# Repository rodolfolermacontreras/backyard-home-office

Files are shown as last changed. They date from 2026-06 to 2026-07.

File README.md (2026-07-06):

# Autonomous WorkPod

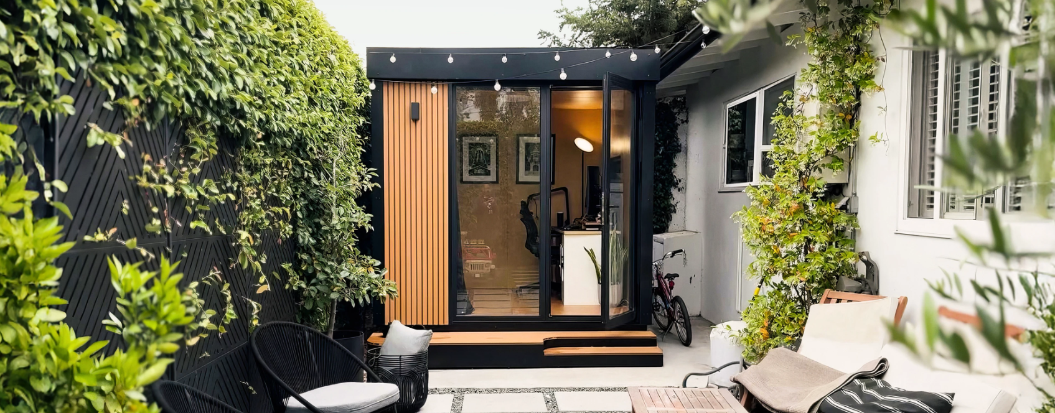
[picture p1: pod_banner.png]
Autonomous WorkPod


Your office is 5 steps from the house. Plug one cable, skip permits, enter deep work.

## What is this?

Open hardware for a backyard office pod. Below permit threshold. One plug. No slab.

Whether you're learning, customizing, or building your own version — the files are here.

## 👶 New to building? Start with the Beginner Guide

If you've never built anything, don't start with the CAD files. Start here:
**[guide/README.md](guide/README.md)** — plain-English checklists, step-by-step build,
schematics, and an El Paso, TX permit + shopping guide.

## Pod Lineup

| | [WorkPod Core](cad/pod-core/) | [WorkPod Pro](cad/pod-pro/) | [WorkPod Versatile](cad/pod-versatile/) |
|---|---|---|---|
| Floor area | 80 sqft | 102 sqft | 105 sqft |
| Ceiling height | 7.25' flat | 6.8'–9.3' sloped | 7.25' flat |
| Foundation | 4 adjustable feet | 6 adjustable feet | 6 adjustable feet |
| Weight capacity | 2.3 tons | 2.9 tons | 2.9 tons |
| Outlets | 2 wall | 2 wall + 1 floor | 5 wall |
| Lighting | 1 ceiling light | 1 ceiling light | 4 ceiling lights |
| Ethernet | 2 ports | — | 2 ports |
| Ventilator | — | Yes | Yes |
| Glass walls | 1 | 1 | 3 |
| Comfort range | — | 45–100°F | 45–100°F |
| Installation | 1–2 days | 1–2 days | 1–2 days |

All models: single outdoor cable from house, no excavation, no concrete, 5° slope tolerance, 7-layer wall system.

## Repo Layout

```
cad/                  3D design files
  pod-pro/            WorkPod Pro
    step/             STEP files (opens in any CAD tool)
    stl/              STL files for 3D printing
  pod-versatile/      WorkPod Versatile
    step/
    stl/
  pod-core/           WorkPod Core
    step/
    stl/

electronics/          Electrical system
  bom/                Electronics parts list

bom/                  Full bill of materials (all parts, prices, links)
```

## Big Files: Git LFS

This repo uses **Git LFS** for CAD, STL, STEP, PCB, video, and PDF files.
Install LFS once before cloning or pushing:

```bash
brew install git-lfs     # macOS
git lfs install
git clone https://github.com/autonomous-ai/autonomous-pod.git
```

## Want to Contribute?

- Upload CAD to [cad/](cad/) with STEP export
- Open an Issue if something is broken or unclear

See [CONTRIBUTING.md](CONTRIBUTING.md) for details.

## License

- Hardware, CAD, docs — **[CC BY-NC-SA 4.0](LICENSE)**
- Firmware, code — **[PolyForm Noncommercial 1.0.0](LICENSE-CODE)**

Plain-English summary: **[LICENSE.md](LICENSE.md)**

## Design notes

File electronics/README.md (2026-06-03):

# Electronics

Electrical system for the WorkPod Pro.

## System Overview

One outdoor cable runs from the house. Inside:
- 3 grounded wall outlets
- 1 ceiling light (LED)
- 1 ventilator (120V)
- 2 Ethernet ports (pass-through to home network)

Optional: solar panel roof add-on with charge controller.

## Files

`bom/parts.csv` — electronics components list

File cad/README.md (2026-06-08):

# CAD

3D design files for all pod variants.

## Folders

```
pod-pro/          WorkPod Pro
  step/           STEP exports (opens in any CAD tool)
  stl/            STL exports for 3D printing
pod-versatile/    Pod Versatile (Studio Pod)
  step/
  stl/
pod-core/         Pod Core
  step/
  stl/
```

## File Naming

`part-name_v1.stp`, `panel-exterior-left_v2.stl`

## Contributing CAD

- Always export and upload `.stp` to the relevant `step/` folder
- Export `.stl` to the relevant `stl/` folder for 3D printing

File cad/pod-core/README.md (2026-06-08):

# WorkPod Core — CAD Files

Compact backyard office. Simple, distraction-free workspace.

| | |
|---|---|
| Floor area | 80 sqft |
| Ceiling height | 7.25' flat |
| Foundation | 4 adjustable feet, 5° slope |
| Weight capacity | 2.3 tons |
| Electrical | 2 wall outlets, 1 ceiling light, 2 Ethernet ports |
| Installation | 1–2 days, no slab required |

## Folders

- `step/` — STEP files (opens in Fusion 360, FreeCAD, SolidWorks, etc.)
- `stl/` — STL files for 3D printing or previewing

## Parts

| File | Description |
|---|---|
| `workpod-mini-assembly` | Full assembly |
| `adjustable-base` | Foundation adjustable foot base |
| `door` | Door assembly |
| `floor-bar-back` | Floor frame — back bar |
| `floor-bar-front` | Floor frame — front bar |
| `floor-bar-side` | Floor frame — side bar |
| `floor-bar-support` | Floor frame — support bar |
| `floor-side-left` | Floor frame — left side panel |
| `floor-side-right` | Floor frame — right side panel |
| `wall-glass` | Glass wall panel |
| `wall-cluster-back-1` | Back wall cluster 1 |
| `wall-cluster-back-2` | Back wall cluster 2 |
| `wall-cluster-front` | Front wall cluster |
| `wall-cluster-left-1` | Left wall cluster 1 |
| `wall-cluster-left-2` | Left wall cluster 2 |
| `wall-cluster-right-1` | Right wall cluster 1 |
| `wall-cluster-right-2` | Right wall cluster 2 |
| `roof-cluster` | Roof cluster (main) |
| `roof-cluster-1` | Roof cluster 1 |
| `roof-cluster-2` | Roof cluster 2 |
| `roof-frame-front` | Roof frame — front |
| `roof-frame-left` | Roof frame — left |
| `roof-frame-right` | Roof frame — right |
| `panel-pu-alu` | PU aluminium cladding panel |
| `picomat-back` | Picomat foundation — back |
| `picomat-front-left` | Picomat foundation — front left |
| `picomat-front-right` | Picomat foundation — front right |
| `outdoor-light` | Outdoor light fixture |
| `outlet-cover` | Outlet cover plate |
| `step-outdoor` | Outdoor step |
| `vent-cover` | Ventilation cover |

## File Naming

`part-name_v1.stp` / `part-name_v1.stl`

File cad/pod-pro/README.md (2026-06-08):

# WorkPod Pro — CAD Files

Mid-sized backyard office. More room to stretch out, sloped ceiling, premium design.

| | |
|---|---|
| Floor area | 102 sqft |
| Ceiling height | 6.8'–9.3' sloped |
| Foundation | 6 adjustable feet, 5° slope |
| Weight capacity | 2.9 tons |
| Comfort range | 45–100°F |
| Electrical | 2 wall outlets, 1 floor outlet, 1 ceiling light, 1 ventilator |
| Extras | Built-in bookshelf |
| Installation | 1–2 days, no slab required |

## Folders

- `step/` — STEP files (opens in Fusion 360, FreeCAD, SolidWorks, etc.)
- `stl/` — STL files for 3D printing or previewing

## Parts

| Group | Files |
|---|---|
| Frames | `frame-main/front/back/left-a/left-b/right-a/right-b/steel_v1` |
| Floor panels | `floor-panel-a/b/c_v1` |
| Wall panels | `wall-back-a/b/c_v1`, `wall-left-a/b/c/d_v1`, `wall-right-a/b/c_v1` |
| Roof panels | `roof-panel-a/b/c/d_v1` |
| Door | `door-assembly_v1` |
| Foundation | `foundation-post-base_v1` |
| Cladding | `cover-composite_v1`, `vinyl-cladding_v1`, `trim-metal_v1` |
| Electrical | `electrical-cabinet_v1` |
| Furniture | `furniture-bookshelf_v1` |

## File Naming

`part-name_v1.stp` / `part-name_v1.stl`

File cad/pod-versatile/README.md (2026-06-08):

# WorkPod Versatile — CAD Files

Large creative studio. Three full glass walls, maximum light, configured as a backyard homelab or studio.

| | |
|---|---|
| Floor area | 105 sqft |
| Ceiling height | 7.25' flat |
| Foundation | 6 adjustable feet, 5° slope |
| Weight capacity | 2.9 tons |
| Comfort range | 45–100°F |
| Electrical | 5 wall outlets, 4 ceiling lights, 2 Ethernet ports, 1 ventilator |
| Glass walls | 3 full glass walls |
| Installation | 1–2 days, no slab required |

## Folders

- `step/` — STEP files (opens in Fusion 360, FreeCAD, SolidWorks, etc.)
- `stl/` — STL files for 3D printing or previewing

## Parts

| Group | Files |
|---|---|
| Full assembly | `studio-pod-assembly_v1` |
| Foundation | `foundation-adjustable-base_v1` |
| Floor base frames | `floor-base-frame-main/back/front/mid/left-a/left-b/right-a/right-b_v1` |
| Floor panels | `floor-panel-a/b/c_v1` |
| Ceiling panels | `ceiling-panel-1/2/3_v1` |
| Roof panels | `roof-panel-a/b/c_v1`, `roof-bitumen_v1` |
| Roof frames | `roof-frame-1/2_v1`, `roof-frame-rod-1/2_v1` |
| Walls | `wall-left-corner-1/2_v1`, `wall-left-mid_v1`, `wall-left-window_v1` |
| | `wall-right-corner-1/2_v1`, `wall-right-mid_v1`, `wall-right-door_v1`, `wall-window_v1` |
| Cladding | `panel-pu_v1`, `cover-pvc-1/2/3_v1` |
| Ventilation | `vent-cover_v1` |
| Electrical | `electrical-cabinet_v1` |
| Furniture | `furniture-1/2/3/4_v1` |

## File Naming

`part-name_v1.stp` / `part-name_v1.stl`

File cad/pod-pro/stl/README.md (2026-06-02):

# STL Files

3D printable parts — brackets, clips, and small hardware.

Naming: `part-name_v1.stl`

Test print at 0.2mm layer height before submitting.

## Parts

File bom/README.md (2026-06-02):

# Bill of Materials

Complete parts list for the WorkPod Pro.

## Files

- `parts.csv` — all parts with quantities, suppliers, and part numbers
- `suppliers.md` — supplier notes and alternatives

## Categories

- Structure (panels, fasteners, seals)
- Foundation (feet, hardware)
- Electrical (cable, outlets, light, ventilator, Ethernet)
- Interior (bookshelf, door hardware)
- Optional: solar panel kit, HVAC

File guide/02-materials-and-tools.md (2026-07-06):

# 2. 🛒 Materials & Tools Checklist

Print this page and tick the boxes as you buy. Prices are rough El Paso estimates (2026) to
help you budget — not exact quotes.

> 💡 The official parts list is in [`../bom/parts.csv`](../bom/parts.csv). This page turns it
> into plain-English shopping with **where to buy in El Paso**.

---

## 💵 Rough total budget (WorkPod Core, DIY)

| Category | Rough cost |
|---|---|
| Wall/roof/floor panels (SIPs or framed) | $3,000 – $6,000 |
| Glass wall + door | $800 – $1,800 |
| Adjustable feet + hardware | $200 – $500 |
| Electrical parts (you supply) | $300 – $600 |
| Electrician labor + permit | $800 – $2,000 |
| Mini-split AC (El Paso must-have) | $700 – $1,500 |
| Tools (if you own none) | $400 – $900 |
| **Ballpark total** | **≈ $6,500 – $13,000** |

---

## 🧱 PART A — Structure (the "kit")

You have two paths. Pick one:

- **Path 1 — Order finished panels (easiest):** Have a **SIP (Structural Insulated Panel)**
  supplier cut panels to the CAD dimensions, including window/door openings. You just bolt them.
- **Path 2 — Build framed walls (cheaper, more work):** Standard 2×4 frame + rigid foam +
  plywood. More cutting, more skill.

### Structure shopping list
- [ ] Exterior wall panels — **8** (per BOM)
- [ ] Interior wall panels — **8**
- [ ] Roof panels — **4**
- [ ] Floor panel — **1**
- [ ] Panel connector bolts — **M10 × 40 mm stainless**, qty ~48
- [ ] Structural sealant — silicone, weatherproof — **3 tubes**
- [ ] Glass wall: **tempered glass panel(s)**, 5/16" thick (order to size from a glass shop)
- [ ] Window frame + window seals
- [ ] Door assembly + door hardware (handle/lock set)

**Where:** SIP suppliers (Premier SIPs, Extreme Panel, or a Texas fabricator — send them the
STEP files). Bolts/sealant: Home Depot, Lowe's, or Fastenal. Glass: any El Paso glass shop
(tempered **must** be cut before tempering, so give final sizes).

---

## 🦶 PART B — Foundation (no concrete!)

- [ ] Adjustable feet — **4** for Core (6 for Pro/Versatile) — screw-jack / adjustable post base
- [ ] Foot mounting bolts — **M12 × 60 mm zinc-plated**, qty ~24
- [ ] Gravel / paver pads (a solid pad under each foot) — 4 small bags of paver base + 4 patio
      pavers work well
- [ ] Landscape fabric (optional, stops weeds under the pod)

**Where:** Home Depot / Lowe's garden + hardware aisles.

---

## ⚡ PART C — Electrical (you buy, electrician installs)

- [ ] Outdoor cable — **12/2 UF-B direct-burial**, length = distance house→pod **+ 10 ft slack**
- [ ] Wall outlets — **NEMA 5-15R grounded**, qty 2 (Core) — get **GFCI** for wet-area safety
- [ ] Ceiling light — **LED panel, 12 W, ~4000K**, qty 1
- [ ] Small subpanel or weatherproof junction box + a **20A breaker**
- [ ] Outdoor-rated disconnect (electrician will advise)
- [ ] Ethernet: **Cat6 cable + 2 RJ45 keystone jacks** (optional, for fast internet)
- [ ] Conduit + fittings where cable is above ground

**Where:** Home Depot / Lowe's or an electrical-supply house. **Let your electrician confirm
the exact list for the permit.**

---

## ❄️ PART D — Comfort (El Paso essentials)

- [ ] **Mini-split AC 6,000–9,000 BTU** (best) — *or* a portable AC that fits max 22"L × 20"W × 88"H
- [ ] Weatherstripping for door
- [ ] Small dehumidifier (optional)

---

## 🧰 PART E — Tools

Own none? Rent the big ones from Home Depot Tool Rental or Sunbelt.

### Must-have
- [ ] Cordless **drill** + **impact driver**
- [ ] **Metric socket set** (for M10 and M12 bolts) + hex bits
- [ ] **Circular saw** or **track saw** (cutting panels/plywood)
- [ ] **Tape measure**, **pencil/marker**, **speed square**, **chalk line**
- [ ] **Level** — a 4 ft level *and* ideally a **laser level** (critical for leveling the feet)
- [ ] **Caulk gun** (for sealant)
- [ ] **Safety glasses**, **work gloves**, **dust mask**, **hearing protection**

### Nice-to-have
- [ ] **Miter saw** (clean framing cuts)
- [ ] **Jigsaw** (curved cuts / openings)
- [ ] **Torque wrench** (bolt to spec, don't overtighten)
- [ ] **Clamps**, **ladder**, **utility knife**
- [ ] **Angle grinder** with metal blade (if trimming aluminum/composite)

### Only if you DIY the wiring (else the electrician brings these)
- [ ] Wire strippers, voltage tester, fish tape

---

## ✂️ Getting materials cut to the right size

| Material | Where / how |
|---|---|
| SIP / composite panels | Factory cuts them to your CAD dimensions — **best option** |
| Plywood / OSB / lumber | Home Depot & Lowe's make **free/cheap straight cuts** at the panel saw |
| Precise panels to CAD | Local cabinet/millwork shop or CNC service — send the **STEP files** |
| Tempered glass | Glass shop cuts to size **before** tempering — give exact dimensions |
| Aluminum extrusion | Buy pre-cut to length (80/20 Inc, TNUTZ, Misumi) |

Next → **[03-step-by-step-build.md](03-step-by-step-build.md)**

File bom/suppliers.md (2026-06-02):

# Suppliers

## Notes

Most structural components ship with the WorkPod Pro kit.
Customer-supplied items: outdoor electrical cable, HVAC unit.

## Customer-Supplied

| Item | Recommendation |
|---|---|
| Outdoor cable | 12/2 UF-B from local hardware store — length depends on your house-to-pod run |
| Portable AC | Any unit fitting max 22"L × 20"W × 88"H with 5.9" exhaust duct |
| Mini-split | Any 6,000–9,000 BTU mini-split for hot climates |

## Hardware Substitutions

- Panel bolts: M10 × 40mm stainless steel hex cap (standard hardware store)
- Foot mounting: M12 × 60mm zinc-plated (standard)

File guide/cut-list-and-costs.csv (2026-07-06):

Phase | Category | Item | Size (from CAD/BOM) | Qty | Unit | Est Unit Cost USD | Est Line Cost USD | Where to Buy (El Paso) | Notes
Structure | Panels | Exterior wall panel | ~7.7 ft tall x ~2 in thick | 8 | ea | 300 | 2400 | SIP supplier / local fabricator | Cut to CAD; DIY 2x4+foam is cheaper
Structure | Panels | Interior wall panel | ~7.7 ft tall | 8 | ea | 120 | 960 | SIP supplier / fabricator | Pairs with exterior panel
Structure | Panels | Roof panel | ~8.4 ft wide | 4 | ea | 250 | 1000 | SIP supplier / fabricator | Flat roof (Core)
Structure | Panels | Floor panel | ~8.4 x 11.3 ft | 1 | ea | 400 | 400 | SIP supplier / fabricator | Sits on floor frame
Structure | Fasteners | Panel connector bolt M10 x 40mm | M10 x 40mm stainless | 48 | ea | 0.80 | 38 | Home Depot / Lowe's / Fastenal | Stainless hex cap
Structure | Sealant | Structural sealant | Silicone weatherproof | 3 | tube | 8 | 24 | Home Depot / Lowe's | Seal every outside seam
Foundation | Feet | Adjustable foot | ~11 in sq base ~12.7 in tall | 4 | ea | 60 | 240 | Home Depot / Lowe's | Screw-jack / adjustable post base
Foundation | Fasteners | Foot mounting bolt M12 x 60mm | M12 x 60mm zinc | 24 | ea | 0.90 | 22 | Home Depot / Lowe's / Fastenal
Foundation | Pads | Paver pad + gravel | 16x16 in paver + base | 4 | set | 15 | 60 | Home Depot / Lowe's garden | One firm pad under each foot
Window | Glass | Tempered glass panel | 5/16 in tempered ~33 x 89 in | 1 | ea | 500 | 500 | Local glass shop | Order to exact opening AFTER wall is built
Window | Frame | Window frame | Fits glass leaf | 1 | set | 150 | 150 | Glass shop / fabricator
Window | Seal | Window seal |  | 1 | set | 40 | 40 | Glass shop / hardware
Door | Door | Door assembly | Right or left hand | 1 | ea | 400 | 400 | Fabricator / home center | Confirm swing direction
Door | Hardware | Door hardware | Handle + lock set | 1 | set | 60 | 60 | Home Depot / Lowe's | Exterior-rated lockset
Electrical | Cable | Outdoor cable 12/2 UF-B | Direct burial | 50 | ft | 1.20 | 60 | Home Depot / Lowe's / supply house | Length = house to pod + 10 ft slack
Electrical | Outlets | Wall outlet GFCI | 15A 125V NEMA 5-15R | 2 | ea | 20 | 40 | Home Depot / Lowe's | GFCI for damp-location safety
Electrical | Light | Ceiling LED light | 12W 4000K panel | 1 | ea | 40 | 40 | Home Depot / Lowe's | Add a wall switch by the door
Electrical | Panel | Subpanel + 20A breaker | Small load center | 1 | set | 120 | 120 | Home Depot / supply house | Electrician confirms
Electrical | Disconnect | Weatherproof disconnect | Outdoor rated | 1 | ea | 40 | 40 | Home Depot / supply house | Where cable enters pod
Electrical | Conduit | Conduit + fittings | As needed | 1 | lot | 60 | 60 | Home Depot / Lowe's | Protect above-ground cable
Electrical | Data | Ethernet Cat6 + keystones | Cat6 + 2 RJ45 | 1 | set | 40 | 40 | Home Depot / Amazon | Optional; low-voltage no permit
Comfort | HVAC | Mini-split AC | 6000-9000 BTU | 1 | ea | 1000 | 1000 | Home center / HVAC supplier | El Paso essential; or portable AC
Labor | Permit | Electrician labor + electrical permit |  | 1 | job | 1400 | 1400 | Licensed electrician | Includes ~200 dollar permit deposit
Tools | Kit | Starter tool kit | Drill/driver/saw/level/etc | 1 | set | 650 | 650 | Home Depot / Harbor Freight | Skip if you already own tools; rent big items
TOTAL |  | Estimated project total (excl. tax) |  |  |  |  | 9744 |  | Panels are the biggest variable - DIY framed walls can cut this a lot

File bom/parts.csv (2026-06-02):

Category | Part | Description | Quantity | Unit | Supplier | Notes
Structure | Exterior wall panel |  | 8 | ea
Structure | Interior wall panel |  | 8 | ea
Structure | Roof panel |  | 4 | ea
Structure | Floor panel |  | 1 | ea
Structure | Panel connector bolt | M10 × 40mm | 48 | ea |  | Stainless
Structure | Structural sealant | Silicone weatherproof | 3 | tube
Foundation | Adjustable foot |  | 6 | ea |  | Max 5° slope
Foundation | Foot mounting bolt | M12 × 60mm | 24 | ea
Electrical | Outdoor cable | 12/2 UF-B | 1 | run |  | Customer supplies
Electrical | Wall outlet | NEMA 5-15R grounded | 3 | ea
Electrical | Ceiling light | LED panel 12W | 1 | ea
Electrical | Ventilator | 120V 50CFM ceiling | 1 | ea
Electrical | Ethernet port | Cat6 RJ45 keystone | 2 | ea
Window | Tempered glass panel | 5/16" tempered | 4 | ea
Window | Window frame |  | 4 | ea
Window | Window seal |  | 4 | set
Door | Door assembly | Right or left | 1 | ea
Door | Door hardware | Handle lock set | 1 | set
Interior | Bookshelf |  | 1 | ea
Optional | Solar panel |  | 1 | ea |  | With panel option
Optional | Solar charge controller |  | 1 | ea |  | With panel option

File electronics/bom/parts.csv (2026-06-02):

Reference | Description | Quantity | Value | Footprint | Supplier | Part Number | Notes
J1 | Outdoor cable inlet | 1 | 20A 125V | NEMA 5-20R |  |  | Main power entry
OUT1 | Wall outlet | 3 | 15A 125V | NEMA 5-15R
L1 | Ceiling light | 1 | LED panel |  |  |  | 12W 4000K
V1 | Ventilator | 1 | 120V 50CFM |  |  |  | Ceiling mount
ETH1 | Ethernet port | 2 | Cat6 | RJ45 keystone
SC1 | Solar charge controller | 1 | optional |  |  |  | For solar panel add-on

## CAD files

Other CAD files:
cad/pod-versatile/step/studio-pod-assembly_v1.stp
cad/pod-pro/step/frame-main_v1.stp
cad/pod-core/step/workpod-mini-assembly_v1.stp
cad/pod-pro/step/door-assembly_v1.stp
cad/pod-versatile/step/floor-base-frame-main_v1.stp
cad/pod-core/step/wall-cluster-back-2_v1.stp
cad/pod-pro/step/wall-right-c_v1.stp
cad/pod-pro/stl/frame-floor_v1.stl
cad/pod-versatile/step/floor-base-frame-right-a_v1.stp
cad/pod-core/step/floor-bar-back_v1.stp
cad/pod-pro/step/frame-steel_v1.stp
cad/pod-versatile/step/roof-panel-c_v1.stp
cad/pod-core/step/wall-glass_v1.stp
cad/pod-pro/step/wall-back-b_v1.stp
cad/pod-versatile/step/wall-left-corner-1_v1.stp
cad/pod-core/step/door_v1.stp
cad/pod-pro/step/wall-left-b_v1.stp
cad/pod-versatile/step/floor-base-frame-front_v1.stp
cad/pod-core/step/adjustable-base_v1.stp
cad/pod-core/step/floor-bar-front_v1.stp
cad/pod-core/step/floor-bar-side_v1.stp
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

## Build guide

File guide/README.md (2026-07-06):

# 🏠 Backyard Home Office — Beginner Build Guide

**Plain-English, step-by-step instructions for building your own backyard office pod in El Paso, TX.**

This guide simplifies the technical CAD files in this repo into something a first-time
builder can actually follow. No jargon. Checklists. Pictures-as-diagrams. One step at a time.

> Based on the [Autonomous WorkPod](../README.md) open-hardware design (CC BY-NC-SA 4.0).

---

## 👶 Never built anything before? Read this first.

You do **not** need to be a carpenter. This design is basically a **big kit of flat panels
that bolt together** and sits on **4 adjustable feet** (like table legs you can screw up/down).
No concrete. No digging. The hardest part is being careful, level, and patient.

**The whole job is 5 phases:**

```
1. PLAN & PERMIT   →   2. BUY STUFF   →   3. FOUNDATION (feet)
        →   4. WALLS + ROOF (bolt panels)   →   5. ELECTRICAL (hire an electrician)
```

Expect **2–4 weekends** for a first-timer working with one helper.

---

## 📚 Read the guide in this order

| # | File | What it covers |
|---|---|---|
| 0 | **You are here** | Overview + pick your model |
| 1 | [01-permits-checklist.md](01-permits-checklist.md) | El Paso permits — what you legally need (do this FIRST) |
| 2 | [02-materials-and-tools.md](02-materials-and-tools.md) | Shopping list: materials + every tool, with checkboxes |
| 3 | [03-step-by-step-build.md](03-step-by-step-build.md) | The actual build, step by step, with diagrams |
| 4 | [04-electrical-wiring.md](04-electrical-wiring.md) | Power wiring diagram + what the electrician does |
| 5 | [05-measurements.md](05-measurements.md) | **Real dimensions** measured from the CAD files |
| 📄 | [cut-list-and-costs.csv](cut-list-and-costs.csv) | **Printable shopping spreadsheet** (opens in Excel/Sheets) |

---

## 🥇 Which pod should a beginner build?

**Build the [WorkPod Core](../cad/pod-core/). It's the simplest.** Here's why:

| | **Core (👈 recommended)** | Pro | Versatile |
|---|---|---|---|
| Size | 80 sq ft interior (~8.4 × 11.3 ft outer) | 102 sq ft | 105 sq ft |
| Feet to level | **4** (easiest) | 6 | 6 |
| Roof | **Flat** (simplest) | Sloped (harder) | Flat |
| Electrical | **2 outlets, 1 light** (simple) | +floor outlet, fan | 5 outlets, 4 lights, fan |
| Glass walls | **1** (fewer to seal) | 1 | 3 (most sealing/leak risk) |
| Best for | **Your first build** | More elbow room | Studio / lots of light |

> ✅ Real dimensions were measured from the CAD files — see **[05-measurements.md](05-measurements.md)**.
> The Core is **≈ 8.4 ft × 11.3 ft outer** (~80 sq ft interior), walls **≈ 7.7 ft tall**. Always
> confirm the exact size against the STEP file before you cut anything.

---

## 🌵 El Paso reality check (important)

- ☀️ **It gets 100°F+ here.** You **will** need a small air conditioner (a 6,000–9,000 BTU
  mini-split, or a portable AC). Budget for it now. See guide 2.
- 🧾 **"Skip permits" is only half true.** The *building* is small enough to skip a building
  permit, but the *electrical hookup* still needs a permit + inspection. See guide 1.
- 🧭 **Don't put a big glass wall facing due west** — afternoon sun will cook you.

---

## 🦺 Safety first (non-negotiable)

- Never work on live electrical. The electrician handles the power connection.
- Two people for lifting wall/roof panels. They are big and awkward.
- Safety glasses + gloves when cutting or drilling. A dust mask for foam/wood.
- Check the weather — don't set roof panels on a windy day.

---

## 🗺️ Big-picture map of the whole project

```mermaid
flowchart TD
    A[1. Plan location + call El Paso One-Stop Shop] --> B[2. Confirm setbacks + HOA]
    B --> C[3. Pull ELECTRICAL permit]
    C --> D[4. Order panels/materials + buy tools]
    D --> E[5. Level the ground roughly]
    E --> F[6. Place + level the 4 adjustable feet]
    F --> G[7. Bolt down floor frame + floor panel]
    G --> H[8. Stand + bolt the wall panels]
    H --> I[9. Set the roof panels]
    I --> J[10. Install door + glass wall + seal everything]
    J --> K[11. Electrician runs cable + wires outlets/light]
    K --> L[12. Final inspection ✅]
    L --> M[13. Add mini-split AC + furniture 🎉]
```

Next → **[01-permits-checklist.md](01-permits-checklist.md)**

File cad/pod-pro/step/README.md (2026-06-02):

# STEP Files

Neutral CAD exchange format — opens in Fusion 360, FreeCAD, SolidWorks, CATIA, and most other tools.

Every part in `../source/` should have a matching `.step` here.

Naming: `part-name_v1.step`

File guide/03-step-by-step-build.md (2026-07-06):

# 3. 🔨 Step-by-Step Build

Follow these phases in order. Don't skip ahead. Check each box before moving on.

> Assumes the **WorkPod Core** (80 sq ft, 4 feet, flat roof). Pro/Versatile are the same idea
> with more feet/panels. Confirm all dimensions against the CAD in `../cad/pod-core/`.

---

## 🗓️ Overview of phases

```mermaid
flowchart LR
    P1[Phase 1\nSite prep] --> P2[Phase 2\nFeet + level]
    P2 --> P3[Phase 3\nFloor]
    P3 --> P4[Phase 4\nWalls]
    P4 --> P5[Phase 5\nRoof]
    P5 --> P6[Phase 6\nDoor + glass + seal]
    P6 --> P7[Phase 7\nElectrical]
    P7 --> P8[Phase 8\nAC + finish]
```

---

## Phase 1 — Prepare the ground 🌍

- [ ] Confirm your spot meets the **setbacks** from guide 1.
- [ ] Call **811** and wait for utilities to be marked (free).
- [ ] Clear grass/debris where the pod will sit.
- [ ] Roughly level the dirt — it does **not** need to be perfect (the feet adjust up to 5°).
- [ ] Lay a paver + a bit of gravel where each foot will land (a firm pad stops sinking).

**Footprint layout (Core, ≈ 8.4 ft × 11.3 ft outer — measured from CAD, see [guide 5](05-measurements.md)):**

```
        11.3 ft (outer)
   ┌───────────────────────┐
   │ ●                   ● │   ● = adjustable foot (x4)
   │      FLOOR AREA       │
   │   ~80 sq ft interior  │   8.4 ft (outer)
   │ ●                   ● │
   └───────────────────────┘
        DOOR side (front)
```

---

## Phase 2 — Place & level the 4 feet 🦶

This is the **most important step**. A level base = everything else lines up.

- [ ] Set the 4 adjustable feet on their pads in the rectangle above.
- [ ] Put your level (or laser level) across them.
- [ ] Screw each foot up/down until **all four tops are at the same height** and flat.
- [ ] Double-check corner-to-corner (diagonals) so it's square, not a parallelogram.

```
   Adjustable foot (side view)
        ┌───┐  ← top plate (bolts to floor frame)
        │   │
        ╪╪╪╪  ← threaded post: twist to raise/lower
        │   │
       ▄▄▄▄▄  ← base plate on paver
   ────────────  ground
```

✅ **Test:** a ball placed on any foot's top plate shouldn't roll off. All four equal height.

---

## Phase 3 — Floor 🟫

- [ ] Bolt the **floor frame bars** together (front/back/side/support bars) into a rectangle.
- [ ] Bolt the floor frame down onto the 4 feet using the **M12 × 60 mm** bolts.
- [ ] Re-check level now that weight is on the feet. Adjust feet if needed.
- [ ] Lay/attach the **floor panel** onto the frame.

```
   FLOOR FRAME (top view)
   ┌──────front bar──────┐
   │        support      │
   ├─────────bar─────────┤   side bars on left/right
   │                     │
   └──────back bar───────┘
     each corner sits on a foot ●
```

---

## Phase 4 — Walls 🧱

Walls are panels that stand up and bolt to the floor and to each other with **M10 × 40 mm** bolts.

- [ ] Start at one **back corner**. Stand the first wall panel, clamp it, bolt its base to the floor.
- [ ] Add the next panel; bolt the two panels **together** along the seam.
- [ ] Work your way around: back → sides → front. Leave the **door** and **glass** openings.
- [ ] Keep checking each panel is **plumb** (perfectly vertical) with your level.
- [ ] Two people: one holds/plumbs, one bolts.

```
   WALL PANELS bolt at seams (top view)
   back-1 ─┬─ back-2
   left-1  │  right-1
   left-2  │  right-2
        front + DOOR + GLASS
   (each "─┬─" = M10 bolts through the seam)
```

**Wall build-up (why it's warm/quiet) — factory "7-layer" panel, simplified:**

```
   OUTSIDE  →  [ weather skin ] [ insulation foam core ] [ inner panel ]  →  INSIDE
                aluminum/PU              thick foam            finished wall
```
DIY framed equivalent: `siding → sheathing → 2×4 + rigid foam → vapor barrier → interior panel`.

---

## Phase 5 — Roof 🟦

⚠️ Two people. Not on a windy day.

- [ ] Bolt the **roof frame** pieces (front/left/right) on top of the walls.
- [ ] Lift the **4 roof panels** up and bolt them to the frame.
- [ ] Make sure the roof overhangs/edges line up so water runs **off**, not in.
- [ ] Add the **vent cover** opening if your model has a ventilator.

```
   ROOF (flat, slight tilt for drainage)
   ┌───────────────────────┐
   │  panel A  │  panel B   │
   ├───────────┼────────────┤
   │  panel C  │  panel D   │
   └───────────────────────┘
     water drains to one edge →
```

---

## Phase 6 — Door, glass & sealing 🚪🪟

- [ ] Install the **door assembly** + handle/lock. Check it opens/closes freely.
- [ ] Install the **tempered glass wall** in its frame with the seals.
- [ ] Run a bead of **weatherproof sealant** along **every** outside seam: wall-to-wall,
      wall-to-roof, wall-to-floor, around door and glass.
- [ ] Add weatherstripping to the door.

✅ **Water test:** spray the outside with a hose and check inside for leaks. Re-seal any drips.

---

## Phase 7 — Electrical ⚡

👉 See **[04-electrical-wiring.md](04-electrical-wiring.md)** for the full diagram.
Short version:
- [ ] Electrician runs the buried **12/2 UF-B** cable from your house panel to the pod.
- [ ] Wires the **outlets**, **light**, and **ventilator** to a small subpanel/junction.
- [ ] Adds **GFCI** protection and a disconnect.
- [ ] City does the **rough** inspection, then the **final** inspection.

---

## Phase 8 — Comfort & finishing ❄️🪑

- [ ] Install the **mini-split AC** (or set up the portable AC) — El Paso essential.
- [ ] Add the bookshelf / furniture.
- [ ] Run **Ethernet** if you want fast internet.
- [ ] Move in your desk, chair, monitor. **Done! 🎉**

---

## 🧯 Common beginner mistakes (avoid these)

| Mistake | Fix |
|---|-----|
| Feet not level | Spend the extra hour in Phase 2 — everything depends on it |
| Overtightening bolts | Snug, not gorilla-tight; use a torque wrench if unsure |
| Skipping the water test | Always hose-test before moving electronics in |
| Big glass wall facing **west** | Orient glass north/east to avoid El Paso afternoon heat |
| Wiring it yourself without a permit | Get the electrical permit — it's required and it's for your safety |
| Setting roof panels solo or in wind | Two people, calm day |

Next → **[04-electrical-wiring.md](04-electrical-wiring.md)**

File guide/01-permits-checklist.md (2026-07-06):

# 1. 🧾 El Paso Permit Checklist

**Do this BEFORE you buy anything.** Confirming the rules first can save you thousands.

> This is guidance, not legal advice. The El Paso One-Stop Shop is the final word.
> **☎️ One-Stop Shop: (915) 212-0104** · 811 Texas Ave · OSSHelp@elpasotexas.gov
> Online portal: https://aca-prod.accela.com/elpaso

---

## ✅ The short version

| Question | Answer for these pods |
|---|---|
| Do I need a **building permit** for the pod itself? | **No** — if it's under 200 sq ft (all 3 pods are). |
| Do I need an **electrical permit**? | **Yes** — the power line from your house is fixed wiring. |
| Do I need to follow **setbacks** (distance from fence)? | **Yes** — always. |
| Do I need **HOA approval**? | **Maybe** — if you have an HOA, ask them too. |

**Why no building permit?** El Paso uses the International Residential Code (IRC). Rule
**R105.2** says a *one-story detached accessory structure of 200 sq ft or less* does not need
a building permit. Your pod is 80–105 sq ft, so the **structure** is exempt. ✅

**Why still an electrical permit?** The exemption above only covers the *box*. Running a
buried power cable from your house panel is **permanent electrical work**, which always needs a
permit and an inspection. (Only a simple extension cord to an existing outdoor plug is exempt —
but that's not enough power for an AC + computer, so don't rely on it.)

---

## 📋 Step-by-step permit checklist

### Step 1 — Find your property's rules
- [ ] Open the **[El Paso Zoning Map](https://experience.arcgis.com/experience/0bccd5cf93c4450ca9f2e8a0e57a2279/)** and type in your address.
- [ ] Write down your **zoning district** (e.g., R-1, R-2, etc.): ________________
- [ ] Open the **[Flood Zone Map](https://city-of-el-paso-open-data-coepgis.hub.arcgis.com/apps/71e293fd6ade47fb93a9f6aad8739299/explore)** — check you're **not** in a flood zone. In a flood zone? Call the city before doing anything.

### Step 2 — Confirm the setbacks (how far from the fence/house)
- [ ] Call the One-Stop Shop and ask: *"What are the rear and side setbacks for a detached
      accessory structure in my zoning district?"* (Often **3–5 ft** from the rear/side property line.)
- [ ] Rear setback: ______ ft   ·   Side setback: ______ ft
- [ ] Measure your yard and mark where the pod legally fits.
- [ ] Keep it **at least the setback distance** from every property line.

### Step 3 — Check the extras
- [ ] **HOA?** If yes, submit the design for approval before building.
- [ ] Don't block a utility easement (usually along the back fence). Ask the city if unsure.
- [ ] Locate underground utilities before placing feet — **call 811 (free "Call Before You Dig")**.

### Step 4 — Pull the electrical permit
- [ ] Decide: are **you** wiring it, or a **licensed electrician**? (Texas usually requires a
      licensed electrician to pull the permit unless you're the homeowner doing your own work —
      **confirm with the city**.)
- [ ] Apply via the **[Citizen Access Portal](https://aca-prod.accela.com/elpaso)** or in person.
- [ ] Budget ~**$200 residential deposit** (credited toward the final permit fee).
- [ ] Schedule the required inspections (rough wiring, then final).

### Step 5 — Keep records
- [ ] Save your permit number: ________________
- [ ] Keep a copy of the permit on-site during the build (required).
- [ ] Book the **final inspection** when wiring is done.

---

## 🚦 Simple decision flow

```mermaid
flowchart TD
    A{Pod under 200 sq ft?} -->|Yes| B[No building permit needed ✅]
    A -->|No| Z[Full building permit required — call city]
    B --> C{Running power from the house?}
    C -->|Yes, buried cable| D[Electrical permit REQUIRED]
    C -->|Only an existing outdoor outlet + cord| E[No electrical permit, but low power]
    D --> F{Have an HOA?}
    E --> F
    F -->|Yes| G[Get HOA approval too]
    F -->|No| H[Confirm setbacks, then BUILD]
    G --> H
```

---

## ❓ Questions to ask when you call (copy/paste)

> "Hi — I want to put a **detached backyard office under 200 square feet** on adjustable
> feet (no concrete slab). Three questions:
> 1. Is that correct that it needs **no building permit** under IRC R105.2?
> 2. What are my **setbacks** for zoning district ____?
> 3. What do I need for an **electrical permit** to run a buried 120V circuit from my house?"

Next → **[02-materials-and-tools.md](02-materials-and-tools.md)**

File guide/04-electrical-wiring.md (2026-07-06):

# 4. ⚡ Electrical Wiring Guide + Schematic

> 🛑 **Safety + legal:** The connection to your house panel is **permanent electrical work**.
> In El Paso it needs an **electrical permit + inspection** (see guide 1). Have a **licensed
> electrician** do the house-panel connection and final hookup. This page helps you *understand*
> and *plan* the system so you can talk to your electrician and pass inspection.

---

## 🔌 How the power flows (simple diagram)

```mermaid
flowchart LR
    HP[🏠 House main panel\n20A breaker] -->|12/2 UF-B\nburied 18 in| DISC[Weatherproof\ndisconnect]
    DISC --> SUB[Small subpanel /\njunction in pod]
    SUB --> GFCI[GFCI protection]
    GFCI --> O1[Outlet 1]
    GFCI --> O2[Outlet 2]
    SUB --> L1[Ceiling LED light\n+ switch]
    SUB --> V1[Ventilator\noptional]
    HN[🏠 Home router] -.Cat6.-> E1[Ethernet jack x2]
```

**In words:** A 20-amp breaker in your house feeds a buried cable to the pod. Inside the pod, a
small subpanel/junction splits power to the **outlets** (GFCI-protected), the **light**, and the
**fan**. Ethernet is separate low-voltage — it just runs alongside for internet.

---

## 🗺️ Physical layout (top view of the Core pod)

```
   ┌─────────────── back wall ───────────────┐
   │  [Light L1 on ceiling, centered]         │
   │                                          │
   │ (Outlet O1)                  (Outlet O2) │
   │                                          │
   │  [Subpanel/junction + disconnect]        │
   │        ▲ cable enters here               │
   └────────┼──────── DOOR ───── GLASS ───────┘
            │
     buried 12/2 UF-B cable
            │
            ▼
      🏠 to house panel
```

---

## 📋 Wiring checklist (what gets installed)

### Cable run (house → pod)
- [ ] **12/2 UF-B** direct-burial cable, buried **~18 inches** deep (electrician confirms local depth)
- [ ] Cable protected by **conduit** where it exits the ground / enters buildings
- [ ] Length = house-to-pod distance **+ ~10 ft slack**

### At the house
- [ ] Dedicated **20A breaker** in the main panel (electrician installs)

### At the pod
- [ ] **Weatherproof disconnect** where the cable enters
- [ ] Small **subpanel or junction box**
- [ ] **GFCI** protection on the outlet circuit (required for damp locations)
- [ ] **2 × wall outlets** (NEMA 5-15R) — Core. (Pro adds a floor outlet; Versatile has 5.)
- [ ] **1 × LED ceiling light** (12W) + wall switch by the door
- [ ] **Ventilator** wired in (Pro/Versatile)
- [ ] Everything **grounded** properly

### Low-voltage (optional, you can DIY this part — no permit)
- [ ] **Cat6** cable from the house router to the pod
- [ ] **2 × RJ45 keystone** jacks on a faceplate

---

## 🔢 Load sanity check (will a 20A circuit handle it?)

| Device | Rough watts |
|---|---|
| Laptop + 2 monitors | ~200 W |
| LED light | ~12 W |
| Ventilator | ~50 W |
| Phone/misc chargers | ~100 W |
| **Subtotal (electronics)** | **~360 W** |
| Mini-split AC (9,000 BTU) | ~800–1,000 W |
| **Total** | **~1,200–1,400 W** |

A 120V / 20A circuit = **2,400 W** max, and you keep continuous load under 80% (~1,920 W).
So one 20A circuit is **usually enough** for a Core with a small mini-split. If you run a
**bigger AC or a space heater**, tell your electrician — you may want a **240V feed** or a
**second circuit**. ✅

---

## 🧾 Inspection steps (so you pass)

```mermaid
flowchart TD
    A[Pull electrical permit] --> B[Electrician runs cable + rough wiring]
    B --> C[Call city for ROUGH inspection\nbefore closing walls]
    C --> D{Pass?}
    D -->|No| B
    D -->|Yes| E[Finish outlets, light, covers]
    E --> F[Call city for FINAL inspection]
    F --> G{Pass?}
    G -->|No| E
    G -->|Yes| H[✅ Legal power — turn it on]
```

- [ ] **Rough inspection** happens **before** you close up walls (so the inspector can see the wiring).
- [ ] **Final inspection** happens after outlets/light/covers are on.
- [ ] Keep the permit on-site both times.

---

## ☀️ Optional: solar add-on

The design supports a roof **solar panel + charge controller** (see BOM "Optional"). This is a
bigger project — get the basic grid power working and inspected first, then add solar later if
you want off-grid backup.

Back to the **[guide index](README.md)**

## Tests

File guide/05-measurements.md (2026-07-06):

# 5. 📏 Real Measurements (from the CAD)

These numbers come from **measuring the actual STEP CAD files** in [`../cad/pod-core/step/`](../cad/pod-core/step/)
with the tool [`../scripts/measure_step.py`](../scripts/measure_step.py). STEP files store geometry
in **millimeters**; the tool converts to inches/feet.

> 🎯 **Honesty note:** individual CAD parts are modeled in different orientations, so a raw
> bounding box isn't always "length × width × height" in the obvious way. The **headline numbers
> below are cross-checked** against several parts and the designer's published spec, so you can
> trust them for planning and shopping. **Before cutting anything, always open the STEP file and
> confirm the exact dimension you need.**

---

## 🏠 WorkPod Core — headline dimensions

| Measurement | Metric | Imperial | Source |
|---|---|---|---|
| **Outer footprint** | ≈ 2.56 m × 3.45 m | **≈ 8.4 ft × 11.3 ft** | floor-bar-front (2552 mm) + floor-bar-side (3455 mm) |
| **Interior floor area** | ≈ 7.4 m² | **≈ 80 sq ft** | published spec (matches footprint minus walls) |
| **Wall height** | ≈ 2.34 m | **≈ 7.7 ft** (7.25 ft interior ceiling) | wall clusters all ≈ 2334–2346 mm |
| **Panel / floor thickness** | ≈ 50 mm | **≈ 2 in** | floor-side panels (50 mm), support bar (60 mm) |
| **Adjustable foot** | 280 mm sq base, ~323 mm tall | **≈ 11 in square, ~12.7 in tall** (adjustable) | adjustable-base part |
| **Foundation feet** | 4 | 4 | Core spec |

**Sanity check:** 8.4 ft × 11.3 ft = ~95 sq ft outer. Subtract the ~2 in walls all around and you
get ≈ **80 sq ft usable** — exactly the published number. ✅

---

## 🪟 Component sizes (useful for planning openings)

| Part | As-modeled size (mm) | Imperial | What it is |
|---|---|---|---|
| Adjustable foot | 280 × 323 × 280 | ~11 × 12.7 × 11 in | Leveling foot base |
| Outdoor light | 80 × 180 × 80 | ~3 × 7 × 3 in | Exterior light fixture |
| Vent cover | 192 × 200 × 408 | ~7.6 × 7.9 × 16 in | Ventilation grille |
| Outlet cover | 107 × 218 × 423 | ~4 × 8.6 × 16.6 in | Outlet plate assembly |
| Floor side panel (L) | 1227 × 2418 × 50 | ~48 × 95 × 2 in | Floor edge panel |
| Floor support bar | 2362 × 60 × 30 | ~93 × 2.4 × 1.2 in | Internal floor joist |
| Glass wall (glazing) | 850 × 2262 × ~15 | ~33.5 × 89 in, ~0.6 in thick | Tempered glass leaf |

> Glass thickness in the BOM is **5/16" tempered**. Order glass **to the exact opening** from a
> glass shop (tempered must be cut *before* tempering).

---

## 🧮 Measure any part yourself

The tool is reusable. To check a dimension before you cut:

```powershell
# One part
python scripts/measure_step.py cad/pod-core/step/floor-bar-side_v1.stp

# Several parts at once
python scripts/measure_step.py cad/pod-core/step/door_v1.stp cad/pod-core/step/wall-glass_v1.stp
```

Output shows Width/Depth/Height in mm, cm, inches, and feet. Works on **any** `.stp` file in this
repo (Core, Pro, or Versatile).

> ⚠️ The **assembly** file (`workpod-mini-assembly_v1.stp`) reports an inflated envelope because
> its parts are laid out in an exploded arrangement — use **individual part files** for real sizes.

---

## 📐 What this means for buying materials

- Your foundation pads (pavers) should sit under a **~8.4 ft × 11.3 ft** rectangle, one under each
  of the **4 feet**, roughly at the corners.
- Wall panels are about **7.7 ft tall** — they fit in a standard pickup/trailer laid flat.
- Everything is **~2 in thick** panels — plan storage and a flat, dry staging area.
- Buy the **glass last**, after the wall opening is built, and measure the real hole.

Next → **[cut-list-and-costs.csv](cut-list-and-costs.csv)** (opens in Excel) · or back to the
**[guide index](README.md)**

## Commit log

2026-06-02 init: WorkPod Pro open hardware repo
    [parts.csv]
2026-06-02 add WorkPod Pro CAD files — STL and STEP organized
    Renamed from original export names (spaces, parens, typos) to
    kebab-case with v1 suffix. Organized into stl/ and step/ by
    component group: frame, wall, floor, roof, door, foundation,
    furniture, electrical, trim, cladding.
    - frame: back, front, left-a/b, right-a/b, main, floor, steel
    - wall: back a/b/c, left a/b/c/d, right a/b/c
    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
    [cover-composite_v1.stl, cover-composite_v1.stp, door-assembly_v1.stl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]
2026-06-03 add Studio Pod CAD files — STL and STEP organized
    86 files from "Studio Pod GitHub/" renamed and moved into
    open-source/cad/studio-pod/stl/ and step/. Source folder removed.
    Fixes: "Celling" → ceiling. Groups: assembly, foundation,
    floor-base-frames, floor, ceiling, roof, walls, cladding, vent,
    electrical, furniture.
    [ceiling-panel-1_v1.stl, ceiling-panel-1_v1.stp, ceiling-panel-2_v1.stl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]
2026-06-03 refactor: flatten repo — move open-source/ to root, remove empty dirs
    All CAD/electronics files moved from open-source/ to repo root.
    Removed placeholder-only directories: classics, learn, setups, thinking,
    tools, cad/concept, cad/drawings, cad/source, electronics/pcb,
    electronics/schematics, electronics/wiring, firmware, foundation, structure.
    Updated README, cad/README, and electronics/README to match.
    [ceiling-panel-1_v1.stl, ceiling-panel-1_v1.stp, ceiling-panel-2_v1.stl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]
2026-06-08 add WorkPod Mini CAD files — STEP and STL organized under cad/workpod-mini/
    [adjustable-base_v1.stl, adjustable-base_v1.stp, door_v1.stl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]
2026-06-08 refactor: reorganize cad into pod-pro, pod-versatile, pod-core
    [adjustable-base_v1.stl, adjustable-base_v1.stp, ceiling-panel-1_v1.stl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]
2026-07-06 Add beginner build guide: checklists, step-by-step, schematics, El Paso permits
2026-07-06 Add real CAD measurements (measure_step.py tool), measurements guide, and cut-list/cost spreadsheet
    [cut-list-and-costs.csv]
